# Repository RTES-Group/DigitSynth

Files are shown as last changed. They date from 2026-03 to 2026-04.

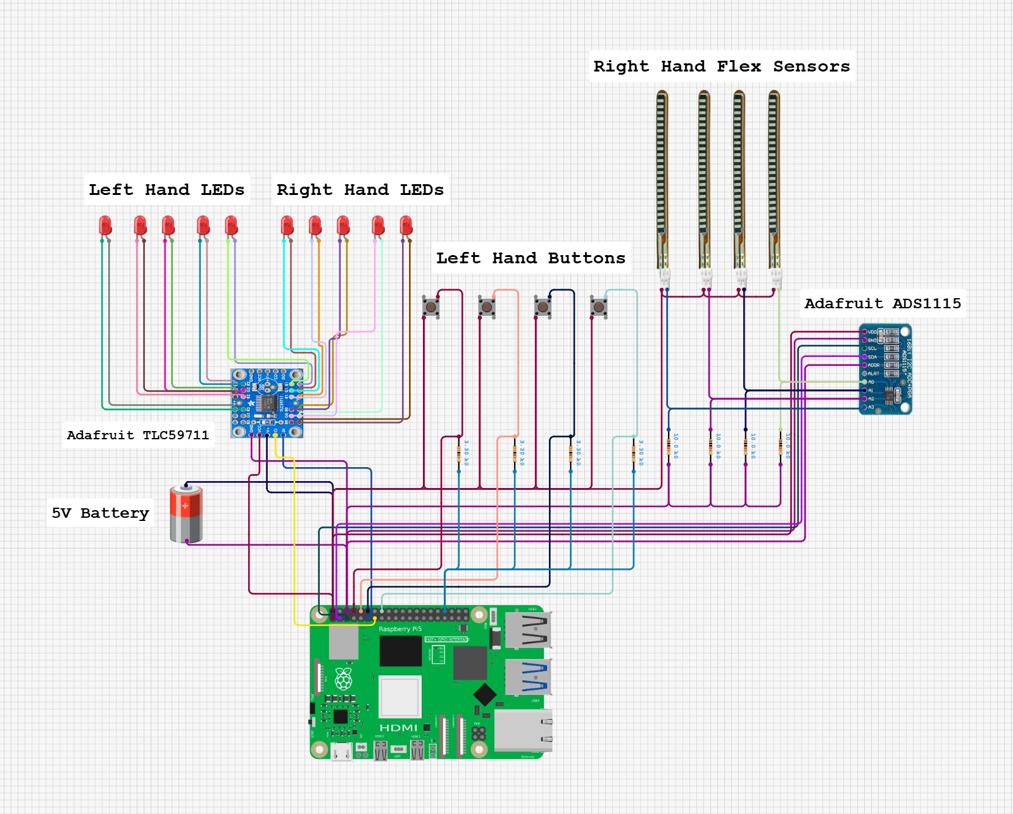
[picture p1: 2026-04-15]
docs/Photo from Becky.jpg

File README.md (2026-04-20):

# DigitSynth

> A real-time wearable audio effects processor built on Raspberry Pi — apply filters and effects to live audio using MIDI control messages with responsive LEDs.

---
##  Features

-  Real-time filtering control for a MIDI synthesiser
-  Low-latency digital signal processing on Raspberry Pi
-  Hardware controls for intuitive parameter adjustment
-  MIDI CC output with adjustable filter parameters
-  Responsive LEDs that react in real-time to parameter changes
-  Open source and fully reproducible
---
## Hardware Requirements
 
### Bill of Materials

The table below outlines the hardware components used in this project. Exact component matches are not required, and suitable alternatives will yield comparable results. However, as the software has been developed specifically for the Raspberry Pi, it is strongly recommended to retain this as the target platform.
 
| Component | Part Number | Quantity | Approx. Cost (unit)|
|---|---|---|---|
| Raspberry Pi 5 | Pi 5 4GB | 1 | £105.60 |
| Adafruit ADS1115 | 1085 | 1 | £11.18 |
| Adafruit TLC59711 | 1455 | 1 | £6.73 |
| Spectra Symbol Flex Sensor FLX| FLX-L-055-123-MP | 4 | £8.51 |
| Tactile Switch, 4.3mm | MCDTS2-1N| 4 | £0.17 |
| Kingbright L-7113IT 5mm 2V Red LED 80mcd | 56-0250 | 8 | £0.08 |
| Pisugar S Plus 5000 mAh Raspberry Pi UPS | Pisugar S Plus | 1 | £29.99 |

A MIDI-receiving device is required to complete the setup, either a hardware synthesiser or a software synthesiser running on a connected laptop. In this project, a Roland JD-Xi synthesiser was used, receiving MIDI directly from the Raspberry Pi over USB-B.

### Wiring Diagram:

Wiring diagram

## Architecture

<details>
<summary>UML class diagram</summary>

DigitSynth UML class diagram

</details>

## Software Requirements

### Toolchain
Our build system is CMake, but we provide a simple top-level Makefile to make things easy. Feel free to run the `cmake` commands manually if you are so inclined. The `install-deps.sh` script will automatically install dependencies required by DigitSynth. 

## Installing
A simple install can be performed using the `.deb` package in the latest release. Download `digitsynth-aarch64.deb`, then run ```bash sudo dpkg -i digitsynth-aarch64.deb``` in your terminal after navigating to the directory into which the archive was downloaded. The standalone binary can also be found in the release.  Note that dependencies still need to be installed. 

## Building

### 1.1 Clone the Repository
 
```bash
git clone https://github.com/RTES-Group/DigitSynth.git
cd DigitSynth
```

OR 

### 1.2 Download the release
Find the latest release on the right-hand side of this page. Download either the `.tar.gz` or `.zip`. After downloading and navigating to the download directory: 

#### `zip`
```bash 
unzip DigitSynth-xx.xx.xx.zip

cd DigitSynth-xx.xx.xx
```

#### `tar.gz`
```bash 
tar -xf DigitSynth-xx.xx.xx.tar.gz

cd DigitSynth-xx.xx.xx
```

### 2. Install Dependencies

#### Dependencies

| Library | Purpose | Source |
|---|---|---|
| IIR Filter Library | Digital IIR filter design and processing | [berndporr/iir1](https://github.com/berndporr/iir1) |
| RtMidi | Real-time MIDI input/output | [thestk/rtmidi](https://github.com/thestk/rtmidi) |
| ADS1115 API | Flex sensor measurement | [berndporr/rpi_ads1115](github.com/berndporr/rpi_ads1115) |
| libgpiod | GPIO management | [ligpiod](https://libgpiod.readthedocs.io/en/latest/building.html) | 
| libasound2-dev | ALSA development headers | [libasound2-dev](https://alsa-project.org/) |

Simply run the `install-deps.sh` script:
```bash 
./install-deps.sh
```

### 3. Enable SPI and I2C on the Raspberry Pi:
SPI must be enabled before the project will run:

```bash
sudo raspi-config
# Navigate to: Interface Options → SPI → Enable
# Navigate to: Interface Options → I2C → Enable
```

### 4. Build the project:

```bash
cd application/
make
```

### 5. Run:
```bash
build/digitsynth
```

---

## Unit tests

To run unit tests: 
```bash 
make test
```
---
## User Guide

A full user guide covering button modes, controls, and MIDI mapping is available here:

 [DigitSynth User Guide](docs/HowToUse.pdf)
 
---
## Demonstration Videos

| Demo 1 | LED Mode Demo | Demo 2 |
|---|---|---|
| Demo 1 (https://youtube.com/shorts/CaOxxR7UvKo) | Demo 2 (https://youtube.com/shorts/K6ZXAT-Ynss) | Demo 3 (https://youtube.com/shorts/oUVmrUkGGP4) |

---
## Social Media

Follow our build journey on Instagram: 

We are also awaiting a write-up on [Hackaday.com](https://hackaday.com) about our project, so keep an eye out on their blog!

---

## Contributing

See the issues tab for a list of potential contributions. In particular, we would welcome expanding support for other synths. 

---
## License

This project is licensed under the **MIT License** — see the [`LICENSE`](LICENSE) file for details.
 
You are free to use, modify, and distribute this project. We just ask that you credit the original authors.

---

## Authors & Acknowledgements

Developed by:

- **Logan Brown** — [GitHub](https://github.com/LoganBrownGU)
- **Becky Clarke** — [GitHub](https://github.com/Becky2603)
- **Dougal Harris** — [GitHub](https://github.com/DougalH1)
- **Finn McConville** — [GitHub](https://github.com/finnmcco)
- **Jamie Wedlinscky** — [GitHub](https://github.com/jwedlinscky)
  
As part of the **Real-Time Embedded Systems** module at **University of Glasgow**, *2026*.

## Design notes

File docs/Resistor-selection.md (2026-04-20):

### Resistor Selection & Voltage Divider Justification

While the flex sensors used in this project have a flat resistance of approximately 12 kΩ (±20%), this value is not universal across all flex sensors. Be sure to check your datasheet before substituting.

**Sensor operating range:** The flat resistance sits in the range 9.6 kΩ – 14.4 kΩ. At full deflection (180°, 8 mm bend radius), the resistance increases by a factor of >4×. We measured the fully-bent resistance to be ~50 kΩ. This yields a total operating range of 9.6 kΩ – 50 kΩ.

**Voltage divider:** A fixed resistor of R₁ = 10 kΩ was chosen, with the flex sensor as R₂ and a 5 V supply:

$$V_{out} = \frac{R_2}{R_1 + R_2} \times V_{in}$$

| State | R₂ | V_out |
|---|---|---|
| Flat | 12 kΩ | 2.73 V |
| Fully bent | 48 kΩ | 4.14 V |

This gives a swing of 1.41 V — a usable and easily resolvable range for the ADC. The maximum output (4.14 V) also remains safely below the ADS1115 maximum analog input voltage of V_DD + 0.3 V = 5.3 V.

**ADC source impedance:** The worst-case source impedance seen by the ADC occurs when the flex sensor is at maximum resistance:

$$R_{source} = R_1 \| R_2 = \left(\frac{1}{10k} + \frac{1}{50k}\right)^{-1} = 8.33\ k\Omega$$

The ADS1115 is a delta-sigma ADC with an input impedance in the range of 10–22 MΩ (depending on PGA gain setting). At 8.33 kΩ, the source impedance is more than three orders of magnitude below this, making its effect on measurement accuracy negligible.

The ADC automatically determines the minimum and maximum voltages, allowing the voltage range to be suitably scaled to the flex sensor.

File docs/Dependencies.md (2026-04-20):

# Dependencies

This document describes all dependencies required to build and run DigitSynth on Raspberry Pi.

A full installation script is available at `DigitSynth/install-deps.sh`.

---

## System Packages

Installed via `apt`:

| Package | Purpose |
|---|---|
| `autotools-dev` | Build toolchain support for autoconf-based projects |
| `autoconf-archive` | Extended macro library for autoconf |
| `libtool` | Generic shared library support |
| `pkg-config` | Compiler flag helper for installed libraries |
| `alsa` | ALSA sound system |
| `libasound2-dev` | ALSA development headers (required by RtMidi) |

---

## libgpiod

**Version:** 2.2
**Source:** https://mirrors.edge.kernel.org/pub/software/libs/libgpiod/
**Purpose:** Linux GPIO access from userspace — used for hardware pin control on the Raspberry Pi.

### Installation

```bash
curl -S https://mirrors.edge.kernel.org/pub/software/libs/libgpiod/libgpiod-2.2.tar.gz -o libgpiod.tar.gz
tar -xf libgpiod.tar.gz
cd libgpiod-2.2/
./configure --enable-bindings-cxx
make
sudo make install
```

> The `--enable-bindings-cxx` flag is required to build the C++ bindings used by this project.

---

## ADS1115 Raspberry Pi Driver

**Source:** https://github.com/berndporr/rpi_ads1115
**Purpose:** Userspace driver for the ADS1115 16-bit ADC over I2C — used to read analogue input from the flex sensors and potentiometers via SPI.

### Installation

```bash
git clone https://github.com/berndporr/rpi_ads1115.git
cd rpi_ads1115/
cmake .
make
sudo make install
```

> Requires I2C to be enabled on the Raspberry Pi. Enable via `sudo raspi-config` → Interface Options → I2C.

---

## iir1 — IIR Filter Library

**Source:** https://github.com/berndporr/iir1
**Purpose:** Digital IIR filter design and processing — used in `FlexDSP` to apply a 4th order Butterworth low-pass filter to flex sensor data.

### Installation

```bash
git clone https://github.com/berndporr/iir1.git
cd iir1
cmake .
make
sudo make install
```

### Usage in this project

Include the filter header with:

```cpp
#include <iir/Butterworth.h>
```

---

## RtMidi

**Source:** https://github.com/thestk/rtmidi
**Purpose:** Real-time MIDI input/output — used to send MIDI CC messages from the glove controller to a connected synthesiser.

### Installation

```bash
git clone https://github.com/thestk/rtmidi.git
cd rtmidi
cmake . -DRTMIDI_API_ALSA=ON -DRTMIDI_API_JACK=OFF
make
sudo make install
```

> Built with ALSA backend enabled and JACK disabled. ALSA is the default audio/MIDI layer on Raspberry Pi OS.

---

## Notes

- All libraries are installed system-wide via `sudo make install` and are picked up automatically by CMake.
- If CMake cannot find a library after installation, run `sudo ldconfig` to refresh the dynamic linker cache.
- Tested on Raspberry Pi OS 64-bit (Bookworm).

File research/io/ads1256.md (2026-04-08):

# ADS1256 ADC

## Clock 
External clock required for continuous conversion. Either crystal oscillator or some other clock source. Speeds specified in datasheet are for a 7.68 MHz clock.  

## Conversion

Falling edge of ~DRDY indicates conversion finished. Send RDATA to begin conversion. ~DRDY goes high either during conversion time or after all data has been read, whichever is sooner. 

## Reading data

### Single
Send RDATA command on DIN while ~DRDY is _low_. Wait and pause SCLK for t<sub>6</sub> (see datasheet) and then read 24 bits (MSB first) on DOUT. 

### Continuous
Send RDATAC after ~DRDY goes low. Wait t<sub>6</sub>. Read 24 bits on DOUT. Subsequent bits will be written by ADC on DOUT as soon as ~DRDY goes low. Note SCLK still has to be clocked, but data will be available as soon as ~DRDY goes low, not after  t<sub>6</sub>. Stop continuous conversion by writing SDATAC or RESET. 

### Standby / One-shot 
Issue STANDBY. ADC will go into low-power standby mode. Keep SCLK low while ~CS is low, otherwise standby will be interrupted. If ~CS is high, SCLK can be modulated. Issue WAKEUP to exit standby, then read as normal. 

## Register managment
Perform synchronisation (see below) after changing register values.

### Writing to registers
Consists of 4 bytes: 2 command bytes, followed by 2 data bytes. 

The 1st command byte is `0101 rrrr`, where `rrrr` is the address of the register to be written to. 

The 2nd command byte is `0000 nnnn`, where `nnnn` is the number of bytes to be written minus 1. 

### Reading from registers
1st command byte is `0001 rrrr`. 

2nd command byte is `0000 nnnn`. 

Wait t<sub>6</sub> after writing the command bytes before reading the data. 

## Synchronisation
Issue SYNC, then WAKEUP.

## Registers 

### STATUS
General settings for ADC. Also contains read-only ID bits and duplicates ~DRDY in bit 0. Set bit 3 to 0 for MSB-first data out, 1 for LSB. Set bit 2 for auto-calibration. Set bit 1 for analogue input buffer enabled. 

### MUX 
Channel selection. Value of bits 6-4 inclusive define active positive channel. Bit 7 selects AINCOM. 6-4 are ignored if AINCOM selected. Value of bits 2-0 define active negative channel. Bit 3 selects AINCOM, behaviour as above. 

### ADCON
Controls clock output, sensor detection, and gain amplifier. Bit 7 0 read-only. Bits 6-5 define clock output and division (00 = clock out off). Bits 4-3 control sensor detection, don't think we care about this. Bits 2-0 define gain amplification. If binary value is $n$, then gain is $2^n$. 

## DRATE
Controls data rate, based on 7.68 MHz clock. Valid values in datasheet. Rates scale linearly with clock rate. 

## IO
Controls GPIO pins. Not relevant for us. 

## OFC[0-2]
Three-byte value representing offset calibration. OFC0 is least significant byte. 

## FSC[0-2]
Three-byte value representing full-scale calibration. OFC0 is least significant byte. 

### 

## Misc.

Issue SELFCAL command to calibrate device after all voltages have settled. 

Command definitions are in Table 24 of the datasheet. 

The value of t<sub>6</sub> is $ 50 \times \tau_\text{CLKIN}$

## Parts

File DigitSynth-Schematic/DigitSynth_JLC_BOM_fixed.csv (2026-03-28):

Designator | Comment | Footprint | LCSC Part # | Mouser Part #
C1 | 100nF | C_0603_1608Metric | C14663
C3 | 100n | C_0603_1608Metric | C14663
C4 | 100n | C_0603_1608Metric | C14663
C5 | 100n | C_0603_1608Metric | C14663
C6 | 100n | C_0603_1608Metric | C14663
C_AVDD_1 | 0.1u | C_0603_1608Metric | C14663
C_AVDD_2 | 10u | C_0805_2012Metric | C15850
C_DVDD_1 | 100n | C_0603_1608Metric | C14663
C_FILT1 | 0.33u | C_0603_1608Metric | C1615
C_FILT2 | 0.33u | C_0603_1608Metric | C1615
C_FILT3 | 0.33u | C_0603_1608Metric | C1615
C_FILT4 | 0.33u | C_0603_1608Metric | C1615
D1 | BZX84C5V6 | SOT-23 | C82471
FB1 | 330Ω | L_0603_1608Metric | C79913
R1 | 1k | R_0603_1608Metric | C21190
R2 | 1k | R_0603_1608Metric | C21190
R3 | 1k | R_0603_1608Metric | C21190
R4 | 1k | R_0603_1608Metric | C21190
R5 | 10k | R_0603_1608Metric | C25804
R6 | 10k | R_0603_1608Metric | C25804
R7 | 10k | R_0603_1608Metric | C25804
R8 | 12k | R_0603_1608Metric | C22790
R9 | 12k | R_0603_1608Metric | C22790
R10 | 12k | R_0603_1608Metric | C22790
R11 | 12k | R_0603_1608Metric | C22790
R12 | 10k | R_0603_1608Metric | C25804
R13 | 10k | R_0603_1608Metric | C25804
R14 | 10k | R_0603_1608Metric | C25804
R15 | 10k | R_0603_1608Metric | C25804
R16 | 5K1 | R_0603_1608Metric | C23186
R17 | 5K1 | R_0603_1608Metric | C23186
U1 | ADS1256IDBR | SSOP-28_5.3x10.2mm_P0.65mm | C28186

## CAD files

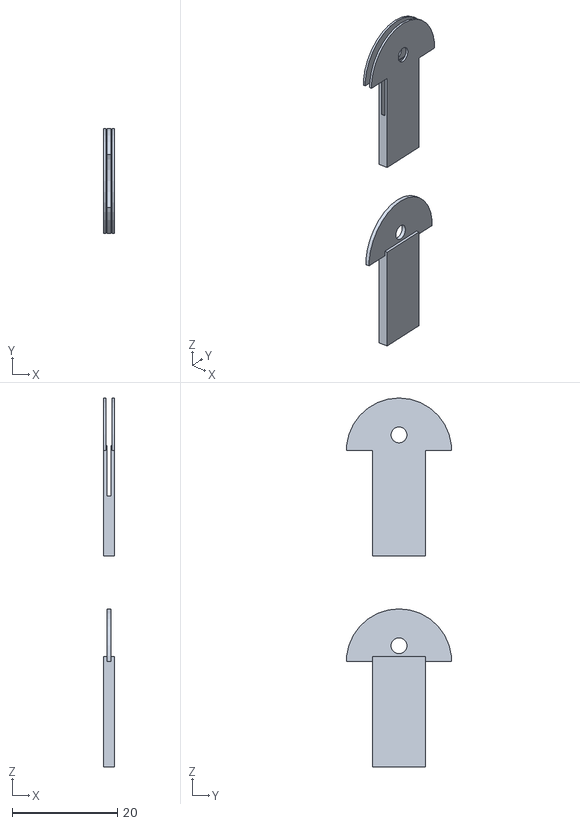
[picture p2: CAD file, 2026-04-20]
GloveMechanicalDesign/proximalSection.stl
2.00 x 19.9 x 70.0

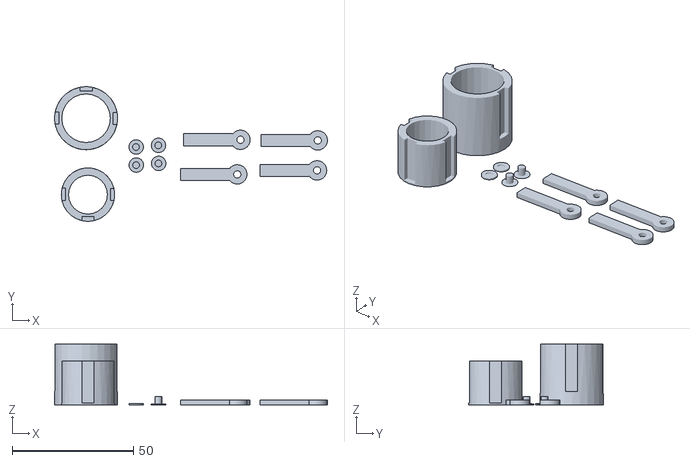
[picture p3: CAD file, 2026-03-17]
GloveMechanicalDesign/FingerJointsTest17_3.stl
112.4 x 55.5 x 25.0

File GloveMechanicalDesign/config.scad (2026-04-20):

// ============================================
// GLOVE MECHANICAL DESIGN PARAMETERS
// ============================================


// ==========================
// FINGER DIMENSIONS (mm)
// ==========================
proximalWidth  = 20;
middleWidth    = 16;

proximalLength = 25;
middleLength   = 20;


// ==========================
// MATERIAL
// ==========================
wallThickness  = 2;


// ==========================
// HINGE CORE GEOMETRY
// ==========================
jointHeight    = 10;                 // hinge radius
jointThickness = wallThickness;      // hinge thickness in X direction


// ==========================
// PIN
// ==========================
pin_d                = 3;
pinRadius            = pin_d / 2;
pin_vertical_offset  = 2;            // mm downward shift


// ==========================
// HINGE POSITIONING
// ==========================
hinge_vertical_offset = 5;           // mm upward shift of hinge connector


// ==========================
// MALE / FEMALE FIT
// ==========================
male_width      = jointThickness * 0.4;
hinge_clearance = 0.3;               // printing tolerance


// ==========================
// CONNECTOR GEOMETRY
// ==========================
connector_bottom_width   = 10;
connector_drop           = 20;
connector_profile_height = 1;
connector_flat_extra     = 1;        // replaces +1 in square height

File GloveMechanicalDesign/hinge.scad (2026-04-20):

include <config.scad>







module hinge_block() {

    difference() {

        // Full cylinder (lying on its side)
        rotate([0,90,0])
            cylinder(
                h = jointThickness,
                r = jointHeight,
                center = true
            );

        // Remove bottom half to create semi-cylinder
        translate([
            -jointThickness,
            -jointHeight,
            -jointHeight
        ])
            cube([
                2*jointThickness,
                2*jointHeight,
                jointHeight
            ]);
    }
}


module hinge_block_female(
    thickness = jointThickness,
    radius = jointHeight,
    male_width = jointThickness * 0.4,
    clearance = 0.3
) {

    difference() {

        // Original semi-cylinder
        difference() {

            rotate([0,90,0])
                cylinder(h = thickness, r = radius, center = true);

            translate([
                -thickness,
                -radius,
                -radius
            ])
                cube([
                    2*thickness,
                    2*radius,
                    radius
                ]);
        }

        // Remove slot for male part
        cube([
            male_width + clearance,
            2*radius,
            2*radius
        ], center=true);
    }
}

module hinge_block_male(
    thickness = jointThickness,
    radius = jointHeight,
    male_width = jointThickness * 0.4
) {
    translate([ male_width/2, 0, 0 ])   // keep in +X
    intersection() {

        // Narrow cylinder
        rotate([0,90,0])
            cylinder(h = male_width, r = radius, center = true);

        // Remove BOTTOM half (keep TOP)
        translate([ -male_width, -radius, 0 ])
            cube([ 2*male_width, 2*radius, radius ]);
    }
}
module hinge_base() {

    difference() {

        // rectangular base
        cube([
            jointThickness,
            2 * jointHeight,
            wallThickness
        ], center=false);

        // subtract matching cylinder curvature
        translate([
            jointThickness/2,
            jointHeight,
            -proximalLength
        ])
            cylinder(
                h = proximalLength + 5,
                d = proximalWidth + 2*wallThickness
            );
    }
}
// =====================
// MODULE: Hinge Pin Hole
// =====================
module hinge_pin_hole() {

    translate([0, 0, (jointHeight / 2) - pin_vertical_offset])
        rotate([0,90,0])
            cylinder(
                h = jointThickness + 2,
                d = pin_d,
                center = true,
                $fn = 60
            );
}



module hingeAssembly()
{
    union() {

        // ----------------------
        // Base (positioned under hinge)
        // ----------------------
        translate([
            -jointThickness/2,
            -jointHeight,
            -wallThickness
        ])
            hinge_base();


        // ----------------------
        // Hinge block with pin hole removed
        // ----------------------
        difference() {

            hinge_block();

            hinge_pin_hole();
        }
    }
}

module hingeAssembly_male()
{
    union() {

        // ----------------------
        // Base
        // ----------------------
        translate([
            -jointThickness/2,
            -jointHeight,
            -wallThickness
        ])
            hinge_base();

        // ----------------------
        // Male hinge block
        // ----------------------
        difference() {

            hinge_block_male();

            // Add the pin hole (same axis as female)
            hinge_pin_hole();
        }
    }
}
module hingeAssembly_female()
{
    union() {

        // ----------------------
        // Base
        // ----------------------
        translate([
            -jointThickness/2,
            -jointHeight,
            -wallThickness
        ])
            hinge_base();

        // ----------------------
        // Female hinge block
        // ----------------------
        difference() {

            hinge_block_female();

            hinge_pin_hole();
        }
    }
}
hingeAssembly_female();
              // printing tolerance
translate([-(hinge_clearance),0,0]) 
hingeAssembly_male();

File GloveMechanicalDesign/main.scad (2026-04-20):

include <config.scad>

use <proximalSection.scad>

middleAssembly();

translate([0,0,70]) 
rotate([0,180,0]) 
proximalAssembly();

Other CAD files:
GloveMechanicalDesign/FingerJoints.bak.dwg
GloveMechanicalDesign/FingerJoints.dwg
GloveMechanicalDesign/middleSection.scad
GloveMechanicalDesign/proximalSection.scad

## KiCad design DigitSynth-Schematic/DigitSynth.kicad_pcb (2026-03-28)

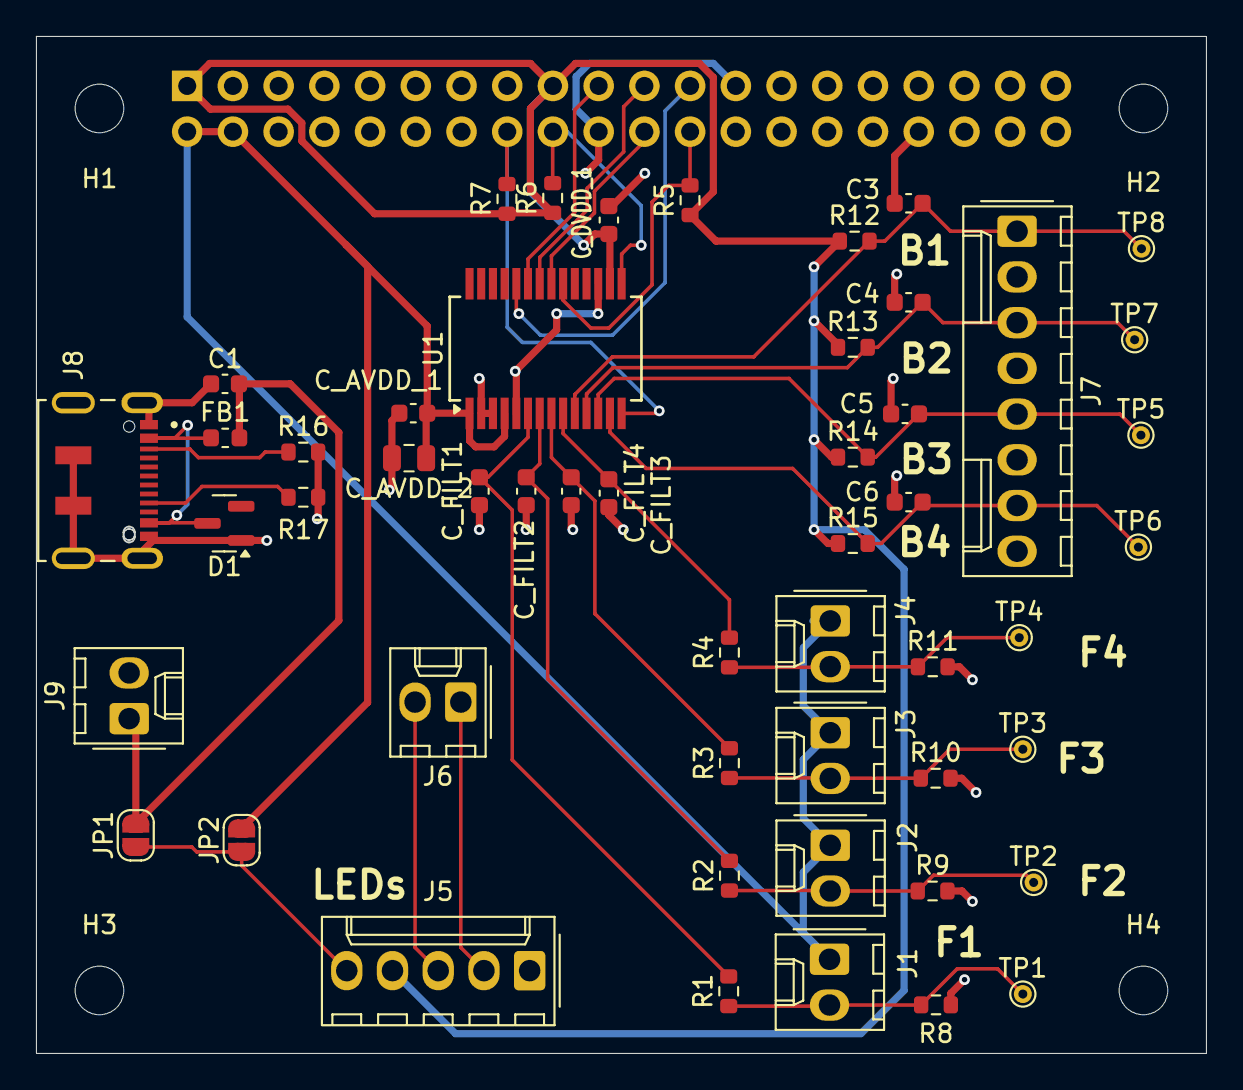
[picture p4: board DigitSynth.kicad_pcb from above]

Board: 2 copper layers, 65.0 x 56.5 mm, 56 parts (1 on the bottom side), 29 nets.

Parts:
C1: 100nF; C_0603_1608Metric
C3, C4, C5, C6: 100n; C_0603_1608Metric
C_AVDD_1: 0.1u; C_0603_1608Metric
C_AVDD_2: 10u; C_0805_2012Metric
C_DVDD_1: 100n; C_0603_1608Metric
C_FILT1, C_FILT2, C_FILT3, C_FILT4: 0.33u; C_0603_1608Metric
D1: BZX84C5V6; SOT-23
FB1: 330Ω; L_0603_1608Metric
H1, H2, H3, H4: MountingHole; MountingHole_2.7mm_M2.5
J1, J2, J3, J4, J6, J9: Conn_01x02_Pin; Molex_KK-254_AE-6410-02A_1x02_P2.54mm_Vertical
J5: Conn_01x05_Pin; Molex_KK-254_AE-6410-05A_1x05_P2.54mm_Vertical
J7: Conn_01x08; Molex_KK-254_AE-6410-08A_1x08_P2.54mm_Vertical
J8: USB_C_Receptacle_USB2.0_JAE; JAE_DX07S016JA1R1500
JP1, JP2: Jumper_2_Open; SolderJumper-2_P1.3mm_Open_RoundedPad1.0x1.5mm
J_RPI1: THD-20-R; PinHeader_2x20_P2.54mm_Vertical
R1, R2, R3, R4: 1k; R_0603_1608Metric
R5, R6, R7, R12, R13, R14, R15: 10k; R_0603_1608Metric
R8, R9, R10, R11: 12k; R_0603_1608Metric
R16, R17: 5K1; R_0603_1608Metric
TP1, TP2, TP3, TP4, TP5, TP6, TP7, TP8: TestPoint; TestPoint_THTPad_D1.0mm_Drill0.5mm
U1: ADS1256IDBR; SSOP-28_5.3x10.2mm_P0.65mm

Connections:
+3V3_PI: C_DVDD_1.1, J5.4, J_RPI1.1, J_RPI1.17, R5.1, R6.1, R7.1, R12.1, R13.1, R14.1, R15.1, U1.16 (DVDD)
+5V_EXT: C1.1, FB1.2, J9.1, JP1.2 (B)
+5V_PI: C_AVDD_1.1, C_AVDD_2.1, J1.1, J2.1, J3.1, J4.1, JP2.2 (B), J_RPI1.2, J_RPI1.4, U1.1 (AVDD), U1.4 (VREFP)
/ADC Flex/ADC_CS: J_RPI1.24, R5.2, U1.20 (~CS)
/ADC Flex/ADC_DRDY: J_RPI1.22, U1.21 (~DRDY)
/ADC Flex/ADC_RESET: J_RPI1.18, R6.2, U1.15 (~RESET)
/ADC Flex/ADC_SYNC_PDWN: J_RPI1.16, R7.2, U1.14 (~SYNC,_~PDWN)
/ADC Flex/BTN_1: C3.1, J7.1, R12.2, TP8.1, U1.10 (AIN4)
/ADC Flex/BTN_2: C4.1, J7.3, R13.2, TP7.1, U1.11 (AIN5)
/ADC Flex/BTN_3: C5.1, J7.5, R14.2, TP5.1, U1.12 (AIN6)
/ADC Flex/BTN_4: C6.1, J7.7, R15.2, TP6.1, U1.13 (AIN7)
/ADC Flex/FLEX1_V: J1.2, R1.1, R8.1, TP1.1
/ADC Flex/FLEX2_V: J2.2, R2.1, R9.1, TP2.1
/ADC Flex/FLEX3_V: J3.2, R3.1, R10.1, TP3.1
/ADC Flex/FLEX4_V: J4.2, R4.1, R11.1, TP4.1
/ADC Flex/SPI0_MISO: J_RPI1.21, U1.22 (DOUT)
/ADC Flex/SPI0_MOSI: J_RPI1.19, U1.23 (DIN)
/ADC Flex/SPI0_SCLK: J_RPI1.23, U1.24 (SCLK)
GND: C1.2, C3.2, C4.2, C5.2, C6.2, C_AVDD_1.2, C_AVDD_2.2, C_DVDD_1.2, C_FILT1.2, C_FILT2.2, C_FILT3.2, C_FILT4.2, D1.1 (A), J5.1, J7.2, J7.4, J7.6, J7.8, J8.A1 (GND), J8.A12 (GND), J8.S1 (SHIELD), J9.2, J_RPI1.6, J_RPI1.9, J_RPI1.14, J_RPI1.20, J_RPI1.25, J_RPI1.30, J_RPI1.34, J_RPI1.39, R8.2, R9.2, R10.2, R11.2, R16.2, R17.2, U1.2 (AGND), U1.3 (VREFN), U1.5 (AINCOM), U1.17 (DGND)
unnamed: D1.3 (K), FB1.1, J8.A4 (VBUS), J8.B4 (VBUS)
unnamed: J5.5, JP1.1 (A), JP2.1 (A)
unnamed: J8.A5 (CC1), R16.1
unnamed: J8.B5 (CC2), R17.1
unnamed: C_FILT1.1, R1.2, U1.6 (AIN0)
unnamed: C_FILT2.1, R2.2, U1.7 (AIN1)
unnamed: C_FILT3.1, R3.2, U1.8 (AIN2)
unnamed: C_FILT4.1, R4.2, U1.9 (AIN3)
SPI2_CLK: J5.2, J6.1
SPI2_DATA: J5.3, J6.2

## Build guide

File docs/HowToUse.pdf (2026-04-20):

# How to Use DigitSynth

Physical Setup
- Left index finger
- LED: TLC59711 pins G0
- Button: Pi GPIO 14
- Left middle finger
- LED: TLC59711 pins G1
- Button: Pi GPIO 15
- Left ring finger
- LED: TLC59711 pins R0
- Button: Pi GPIO 18
- Left pinkie
- LED: TLC59711 pins B1
- Button: Pi GPIO 23
- Right index finger
- LED: TLC59711 pins B0
- Flex sensor: ADC pin A3
- Right middle finger
- LED: TLC59711 pins R2
- Flex sensor: ADC pin A0
- Right ring finger
- LED: TLC59711 pins R1
- Flex sensor: ADC pin A2
- Right pinkie
- LED: TLC59711 pins G2
- Flex sensor: ADC pin A1

How it works
DigitSynth is a wearable MIDI controller that interacts with the Roland JD-Xi synthesiser. It allows the user to trigger chords and shape the resulting sound in real time using finger movements.

Chords are sustained infinitely once triggered, and only stop when switching to a new chord.

The right hand is used to shape the sound. Each flex sensor controls a different synth parameter. The index finger adjusts the cutoff frequency of a low-pass filter, allowing the sound to move from bright and sharp to dull and muted as the finger bends.

The middle and ring fingers control a low-frequency oscillator (LFO) which modulates the filter. The middle finger sets the LFO rate, which determines how quickly the modulation occurs, while the ring finger controls the depth of the LFO i.e. how strong the effect is.

The character of the modulation depends on the shape of the LFO. A sine wave produces smooth changes, a square wave creates sudden switching between values, and the sample-and-hold (SH) mode introduces a random stepped modulation.

The pinkie controls pitch detuning. When held straight, the pitch remains stable. As the finger bends, the pitch becomes increasingly detuned.

Modes of Operation
DigitSynth operates in two modes: a chord mode for live changes between chords, and a normal mode for extended system control.

In chord mode, the four buttons on the left hand each correspond to a specific chord. Pressing a button will immediately switch to that chord. The index finger triggers an Fmaj9 chord, the middle finger plays an Amin11 chord, the ring finger plays a Gsus2 chord, and the pinkie plays a Cmaj7 chord. Pressing the button corresponding to the currently active chord exits chord mode and returns the system to normal mode.

In normal mode, the same buttons are used to control system behaviour. The index finger is used to enter chord mode. The middle finger toggles the LFO on or off. The ring finger cycles through the available LFO shapes (sine, square, and SH). The pinkie switches between the two LED display modes.

LED Behaviour
The LEDs either provide visual feedback or an aesthetic animation, depending on user selection.

In responsive mode, the LEDs communicate the internal state of the system. The left index LED indicates whether the system is in normal mode (on) or chord mode (off). The left middle finger LED shows whether the LFO is enabled (on). The left ring finger LED indicates the current LFO shape using brightness levels: off for sine, medium for square, and full brightness for SH. The left pinkie LED is always on in responsive mode. The brightness of the LEDs on the right hand reflect the position of the flex sensors, giving a visual indication of parameter values.

Alternatively, the LEDs can be set to a ripple mode, where a continuous animated pattern plays across all LEDs. In this mode, no parameter feedback is shown.

Startup Behaviour
On boot, DigitSynth starts in normal mode with an Amin11 chord playing (the chord mapped to the left middle finger). The LEDs are in responsive mode, and the LFO is enabled with a sine wave shape.

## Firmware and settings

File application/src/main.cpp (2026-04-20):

#include "synth-controller.hpp"
#include "tlc59711.hpp"
#include "adc-driver.hpp"
#include "button-driver.hpp"
#include "flex-sensor.hpp"
#include "gpio.hpp"
#include "midi-driver.hpp"
#include "patterns.hpp"
#include "voltage-scaler.hpp"
#include <condition_variable>
#include <iostream>
#include <memory>
#include <mutex>

int main() {
    gpio::setupGpio();
    std::condition_variable c;
    std::mutex m;
    bool done = false;
    
    auto bd = std::make_unique<button_driver::ButtonDriver>();
    bd->registerAllButtonsCallback([&c, &m, &done] () {
        std::unique_lock lock(m);
        done = true;
        lock.unlock();
        c.notify_all();
    });
    
    auto tlc = led_driver::TLC59711("/dev/spidev0.0", 1'000'000);
    auto pattern = led_pattern::PatternRipple(tlc);
    tlc.start();
    SynthController synth(
        tlc,
        pattern,
        std::move(bd),
        std::make_unique<flex_sensor::FlexSensor>(
            std::make_unique<adc_driver::Ads1115Driver>(),
            std::make_unique<voltage_scaler::VoltageScaler>()
        ),
        std::make_unique<midi_driver::MidiDriver>()
    );
   

    getchar();
    
    std::cout <<"stop\n";
    
    return 0;
}

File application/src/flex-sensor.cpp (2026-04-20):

#include "flex-sensor.hpp"
#include "adc-driver.hpp"
#include "voltage-scaler.hpp"
#include <ads1115rpi.h>
#include <array>
#include <memory>
#include <thread>

using namespace flex_sensor;

void FlexSensor::updateIfNeeded() {
    if (!this->callback.has_value()) { return; } 
    
    std::array<ExtensionData, 4> data;
    data[0] = this->vs->scale(this->values[ADS1115settings::AIN0], ADS1115settings::AIN0);
    data[1] = this->vs->scale(this->values[ADS1115settings::AIN1], ADS1115settings::AIN1);
    data[2] = this->vs->scale(this->values[ADS1115settings::AIN2], ADS1115settings::AIN2);
    data[3] = this->vs->scale(this->values[ADS1115settings::AIN3], ADS1115settings::AIN3);
    
    this->n_samples++;
    this->callback.value()(data);
}

uint64_t FlexSensor::getNSamples() {
    return this->n_samples;
}

FlexSensor::FlexSensor(std::unique_ptr<adc_driver::IAdcDriver> adcDriver, std::unique_ptr<voltage_scaler::IVoltageScaler> voltageScaler) 
: adc(std::move(adcDriver)), vs(std::move(voltageScaler)) 
{
    this->adsCallback = [&] (float f) {
        auto prevChannel = this->currentChannel;
        
        switch (this->currentChannel) {
            case (ADS1115settings::AIN0):
                this->currentChannel = ADS1115settings::AIN1;
                break;
                
            case (ADS1115settings::AIN1):
                this->currentChannel = ADS1115settings::AIN2;
                break;

            case (ADS1115settings::AIN2):
                this->currentChannel = ADS1115settings::AIN3;
                break;
 
            case (ADS1115settings::AIN3):
                this->currentChannel = ADS1115settings::AIN0;
                this->updateIfNeeded();
                break;               
        }
        
        this->values[prevChannel] = f;  
        if (!this->running) { return; }
        this->adc->readChannel(this->currentChannel, &this->adsCallback);
    };
}

FlexSensor::~FlexSensor() {
    this->running = false; 
    if (worker.joinable()) { worker.join(); }
}

void FlexSensor::registerCallback(ExtensionCallback callback) {
    this->callback = callback;
}

void FlexSensor::begin() {
    this->worker = std::thread([&] () {this->adc->readChannel(this->currentChannel, &this->adsCallback);}); 
}

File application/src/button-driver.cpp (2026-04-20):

#include "button-driver.hpp"
#include "gpio.hpp"
#include <gpiod.hpp>
#include <thread>

using namespace button_driver;

ButtonDriver::ButtonDriver() {
    for (ButtonIndex i = 0; i < (ButtonIndex) workers.size(); i++) {
        workers[i] = std::thread([&, i] () {
            while (this->running) {
                auto edge = gpio::blockUntilEdge(ButtonDriver::BUTTON_PINS[i], gpiod::line::edge::BOTH);
                
                if (!edge.has_value()) { continue; }
                
                bool val = edge.value() == gpiod::edge_event::event_type::RISING_EDGE;
                this->buttonStatuses[i] = val;
                
                
                if (!val) { continue; }
                if (!this->singleButtonCallback.has_value()) { continue; }
                    
                this->singleButtonCallback.value()(i); 
               
                if (!this->allButtonsCallback.has_value()) { continue; }
                bool allPressed = false;
                for (auto status : buttonStatuses) {
                    if (!status) { allPressed = false; break; }
                    allPressed = true;
                }
                
                if (allPressed) { this->allButtonsCallback.value()(); }
            }
        });  
    }
}

ButtonDriver::~ButtonDriver() {
    this->running = false;
    gpio::cancelLineRequests();
    for (std::thread &t: this->workers) {
        if (t.joinable()) { t.join(); }
    }
}

void ButtonDriver::registerAllButtonsCallback(AllButtonsCallback callback) {
    this->allButtonsCallback = callback;
}

void ButtonDriver::deregisterSingleButtonCallback() {
    this->singleButtonCallback = {};
}


void ButtonDriver::registerSingleButtonCallback(SingleButtonCallback callback) {
    this->singleButtonCallback = callback;
}

void ButtonDriver::deregisterAllButtonsCallback() {
    this->allButtonsCallback = {};
}

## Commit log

2026-02-25 Added flex sensor research file.
2026-02-25 Inital Config File Commit
    [config.scad]
2026-02-25 proximal guard design as well as connector to female hinge
    [proximalSection.scad]
2026-03-03 System Flowchart upload
    Adding the flowchart for the system design showing inputs and outputs from the system
2026-03-04 Add KiCad project structure and schematic
    [ADC_Flex.kicad_sch, Buttons.kicad_sch, DigitSynth.kicad_pcb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]
2026-03-04 Add completed KiCad schematic hierarchy (Pi interface, ADC, LEDs, buttons, power)
    [ADC_Flex.kicad_sch, Buttons.kicad_sch, DigitSynth.kicad_sch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]
2026-03-08 Added SPI driver
2026-03-08 Handle multiple CS pins (#17)
    Still need to decide which pins to use for SPI
2026-03-08 SPI `updateSettings` function
2026-03-11 Thread-safe read/write queues
2026-03-15 Test for SPI hangs
    May be a permissions thing, or something to do with it being unconnected
2026-03-15 ADC settings initialised in constructor #9
2026-03-17 Able to read some value from ADC, seems incorrect
2026-03-17 Added autocad bak files for the 3D design
    [FingerJoints.bak.dwg, FingerJoints.dwg, FingerJointsTest17_3.stl]
2026-03-24 creator destructor, start/stop and pipe wiring with stubs for remaining fucntions
2026-03-25 Updated back to single thread to confirm ripple functionality
2026-03-25 Added functio to block on pin
2026-03-28 KiCad PCB fully routed
    [ADC_Flex.kicad_sch, Buttons.kicad_sch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]
2026-04-02 Rewriting ADC driver
2026-04-02 Rewrite GPIO access and thread wakeup to use libgpiod and condvar
2026-04-03 Fix narrowing conversion and LEDFrame references for clean build
2026-04-05 implemented button press pipeline in synth logic layer
2026-04-06 test for SynthController class button press handling
2026-04-06 added flex sensor event handling in synth logic layer
2026-04-08 integrating LED updates into button logic
2026-04-08 test for led integration
2026-04-08 working test for LED integration with buttons
2026-04-08 LED pattern switching triggered by button presses
2026-04-13 updated flex sensor handling for correct data packet from flex driver
2026-04-13 Archive and print testing log
2026-04-13 fix tlc declaration in flex sensor test
2026-04-13 `gpio` no longer causes error (#56)
    Removed `gpio::registerCallback` as unused.
    Removed worker thread --- poorly implemented and was the cause of the
    error due to it not being joined before program termination.
    [gpio.cpp, main.cpp]
2026-04-13 remove redundant methods in Midi driver class
2026-04-14 `cancelLineRequests` function to make sure that threads conclude
    When `cancelLineRequests` is called, waiting on edge will exit after
    next timeout and send a dummy falling edge.
    Should probably replace dummy edge with `optional`.
    [button-driver.cpp, gpio.cpp, main.cpp]
2026-04-14 Flex sensors control LEDs
    [flex-sensor.cpp, main.cpp]
2026-04-14 TLC now runs only as fast as it can
    Moved dirty flag reset to _after_ write has concluded.
    Exit update function if dirty flag set.
    [flex-sensor.cpp]
2026-04-14 improved LED logic
2026-04-14 fix LED update logic error
2026-04-15 Update link format for wiring diagram in README
2026-04-15 Add wiring diagram to README
    Added wiring diagram to the README for clarity.
2026-04-18 Changing number of LEDs in ITLC hedder to 8
2026-04-18 Updates to num_LEDs and FRAME_TO_GS to reflect new :ED count of 8
2026-04-18 added in additional comments for clairty on LED mapping
2026-04-18 Updated led controller test to reflect only sing 8LEDs now and tests passed. Added in the Test to the Cmake list to complie and run it.
2026-04-18 Added #include "ITLC59711.hpp" to LedController.hpp
2026-04-18 removed definition of pin number and now uses interface class instead
2026-04-18 Auto voltage ranging
2026-04-18 refine synth logic implementation for first prototype
2026-04-18 Started adding flex sensor interface
2026-04-19 fix button callback name
2026-04-19 fix button driver call in synth controller class
2026-04-19 use led_driver namespace in TLC59711.cpp
2026-04-19 Adding flex sensor unit tests
    Need to create interface for voltage mapping
    [flex-sensor.cpp]
2026-04-19 Added `voltage-scaler`
    Basic unit test for flex-sensor works
    Changed CMakeLists to remove path duplication
    [flex-sensor.cpp, main.cpp]
2026-04-19 rewrite LedController unit test based on new LED rules
2026-04-19 Fixed `led_controller_test`
2026-04-20 rewrite MessageBuilder class for open closed principle: replace switch statement with vector of function objects
2026-04-20 Sorting out ownership (#111)
    SynthController does not need to own an instance of Pattern, so it does
    not.
    Pattern constructor now takes a ILedDriver reference, as all Patterns
    will need to own an ILedDriver. LedController also holds a reference to
    ILedDriver.
2026-04-20 flex sensor uses `unique_ptr` #111
    [flex-sensor.cpp, main.cpp]
2026-04-20 Update LedController.hpp with led namespace and interface
2026-04-20 Rewrote TLC to use `gpio` driver
2026-04-20 Removed double-instantiation of ButtonDriver
2026-04-20 Update parts list and dependencies in README
    Updated the quantity of Kingbright L-7113IT LED in the parts list and added libasound2 to the dependencies section. Minor formatting adjustments in the contributing section.
2026-04-20 Remove KiCad backups folder from DigitSynth-Schematic folder
2026-04-20 Updated patterns.cpp to reflect the ordering of LEDs in the pyhsical setup as given by LEDController.hpp
2026-04-20 Restore Resistor Selection & Voltage Divider Justification
    Reintroduced the Resistor Selection & Voltage Divider Justification section with detailed explanations and calculations regarding flex sensor resistance and ADC source impedance.
